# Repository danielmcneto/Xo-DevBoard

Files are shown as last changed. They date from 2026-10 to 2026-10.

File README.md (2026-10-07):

# Xo-DevBoard

Xo-DevBoard Rendering

**Xo-DevBoard** is a compact, custom ESP32-WROOM-32 development board featuring an integrated display header designed specifically for real-time sensor debugging without relying on a tethered PC monitor.

---

## The Problem & The Solution

**Tired of constantly alt-tabbing to your Serial Monitor just to check if a sensor value is updating?**  
Traditional devboards force you to keep your laptop plugged in during basic hardware debugging. The **Xo-DevBoard** solves this by providing a dedicated display interface (J4) directly on the board. Plug in a mini OLED or TFT screen, flash your code, and read live telemetry anywhere—completely standalone.

---

## Features & Hardware Highlights

* **Brain:** ESP32-WROOM-32 module (Wi-Fi + Bluetooth BLE).
* **Integrated Display Interface (J4 Header):** Dedicated 8-pin connector supporting I2C/SPI display modules.
* **On-board USB-to-UART Converter:** CH340C chip with an automated DTR/RTS auto-reset circuit
* **Power Management:** Modern USB-C connector with ESD/overcurrent protection.
* **User Controls:** Tactile Reset (EN) and Boot (GPIO0) buttons.
* **Full Breakout:** Dual 1x15 pin headers breaking out all usable ESP32 GPIOs for breadboard prototyping.

---

<!--## Display Header Pinout (J4)

The built-in display connector (**J4**) is routed to the following ESP32 pins[cite: 2]:

| Pin # | Header Label | ESP32 GPIO | Typical Usage (I2C / SPI) |
| :---: | :---: | :---: | :---: |
| 1 | GND | GND | Ground[cite: 2] |
| 2 | 3.3V | +3.3VA | Power Supply (3.3V)[cite: 2] |
| 3 | D18 | GPIO18 | SDA (I2C) / MOSI (SPI)[cite: 2] |
| 4 | D23 | GPIO23 | SCL (I2C) / SCK (SPI)[cite: 2] |
| 5 | D2 | GPIO02 | Reset / General IO[cite: 2] |
| 6 | D4 | GPIO04 | Data / Command (DC)[cite: 2] |
| 7 | D5 | GPIO05 | Chip Select (CS)[cite: 2] |
| 8 | 3.3V | +3.3VA | Auxiliary Power[cite: 2] |

--->

## Project Status & Firmware

This repository contains:
1. **KiCad Production Files:** Schematic (`.kicad_sch`), PCB layout (`.kicad_pcb`), and Gerber files for manufacturing.
2. **Starter Firmware:** A C++/PlatformIO demo program that initializes the display, tests onboard peripherals, and renders a `"Hello World!"` telemetry screen.

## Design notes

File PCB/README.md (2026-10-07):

## Here you will find the files of the pcb

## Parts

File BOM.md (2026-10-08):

# Xo-DevBoard – bill of materials

<!-- Generated by Half Life from project cmuv2anbv0cnf01smwlqq86t9. Edits here are overwritten on the next sync. -->
<!-- Generated: 2026-10-08T13:36:38.834Z -->

> [!NOTE]
> This parts list is mirrored from [Half Life](https://halflife.hackclub.com). Editing it here will not change the platform's copy, and the next sync overwrites this file.

| Week | Tier | Parts funding |
| --- | --- | --- |
| Week 1 | Tier 1 | $30.00 |

| Part | What it's for | Qty | Unit | Total | Vendor |
| --- | --- | --- | --- | --- | --- |
| [TFT display](https://www.amazon.com/Display-Module-240x240-Interface-Arduino/dp/B0DN9NMBFW/ref=sr_1_3?sr=8-3) | for the built-in display | 1 | $7.99 | $7.99 | [AMAZON](https://www.amazon.com/Display-Module-240x240-Interface-Arduino/dp/B0DN9NMBFW/ref=sr_1_3?sr=8-3) |
| **Parts subtotal** | — | — | — | **$7.99** | — |
| **Tax & shipping** | — | — | — | **$20.00** | — |
| **Total** | — | — | — | **$27.99** | — |

$2.01 left of the tier's funding.

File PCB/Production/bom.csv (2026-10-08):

Designator | Footprint | Quantity | Value | LCSC Part #
BOOT, RST | SW_Push_SPST_NO_Alps_SKRK | 2 | SW_Push
C3, C4, C6, C7, C8 | 0603 | 5 | 100nF
C5 | CP_EIA-3216-10_Kemet-I | 1 | 10uF/16v
D2 | D_SOD-123 | 1 | B5819W
D3, D4 | 0603 | 2 | LED
J1 | USB_C_Receptacle_HRO_TYPE-C-31-M-12 | 1 | USB_C_Receptacle_USB2.0_16P
J2, J3 | PinHeader_1x15_P2.54mm_Vertical | 2 | Conn_01x15
J4 | PinSocket_1x08_P2.54mm_Vertical | 1 | DISPLAY
Q1, Q2 | SOT-23 | 2 | SS8050
R2, R3 | 0603 | 2 | 5K1
R4 | 0603 | 1 | 1K
R5, R6, R8 | 0603 | 3 | 10K
R9 | 0603 | 1 | 200R
U1 | SOIC-16_3.9x9.9mm_P1.27mm | 1 | CH340C
U2 | ESP32-WROOM-32 | 1 | ESP32-WROOM-32
U3 | SOT-223-3_TabPin2 | 1 | AMS1117-3.3

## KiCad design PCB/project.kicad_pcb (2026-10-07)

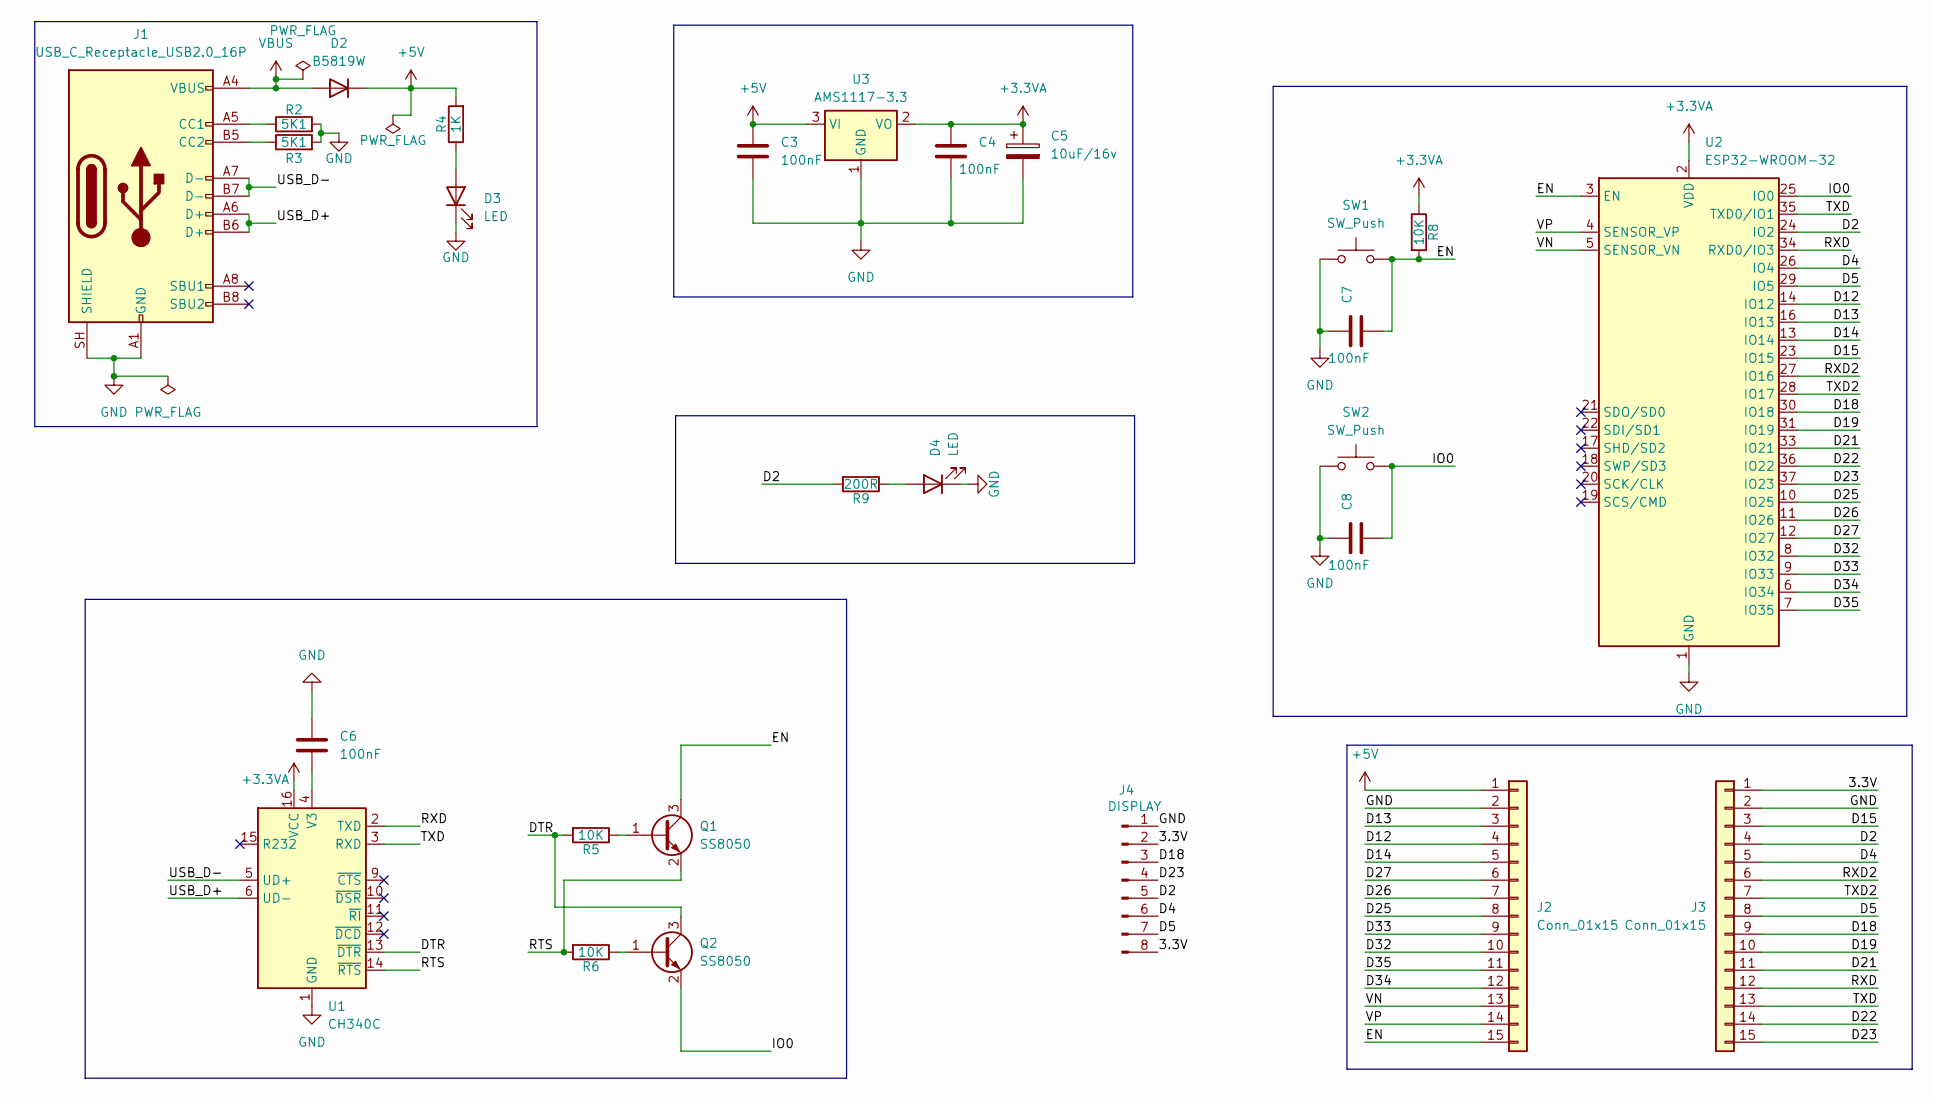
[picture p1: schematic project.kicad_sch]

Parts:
C3, C4, C6, C7, C8: 100nF; C_0603_1608Metric
C5: 10uF/16v; CP_EIA-3216-10_Kemet-I
D2: B5819W; D_SOD-123
D3, D4: LED; LED_0603_1608Metric
J1: USB_C_Receptacle_USB2.0_16P; USB_C_Receptacle_HRO_TYPE-C-31-M-12
J2, J3: Conn_01x15; PinHeader_1x15_P2.54mm_Vertical
J4: DISPLAY; PinSocket_1x08_P2.54mm_Vertical
Q1, Q2: SS8050; SOT-23
R2, R3: 5K1; R_0603_1608Metric
R4: 1K; R_0603_1608Metric
R5, R6, R8: 10K; R_0603_1608Metric
R9: 200R; R_0603_1608Metric
SW1, SW2: SW_Push; SW_Push_SPST_NO_Alps_SKRK
U1: CH340C; SOIC-16_3.9x9.9mm_P1.27mm
U2: ESP32-WROOM-32
U3: AMS1117-3.3; SOT-223-3_TabPin2

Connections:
+3.3VA: C4.1, C5.1, R8.1, U1.16 (VCC), U2.2 (VDD), U3.2 (VO)
+5V: C3.1, D2.1 (K), J2.1, R4.2, U3.3 (VI)
/3.3V: J3.1, J4.2, J4.8
/D2: J3.4, J4.5, R9.2, U2.24 (IO2)
/D4: J3.5, J4.6, U2.26 (IO4)
/D5: J3.8, J4.7, U2.29 (IO5)
/D12: J2.4, U2.14 (IO12)
/D13: J2.3, U2.16 (IO13)
/D14: J2.5, U2.13 (IO14)
/D15: J3.3, U2.23 (IO15)
/D18: J3.9, J4.3, U2.30 (IO18)
/D19: J3.10, U2.31 (IO19)
/D21: J3.11, U2.33 (IO21)
/D22: J3.14, U2.36 (IO22)
/D23: J3.15, J4.4, U2.37 (IO23)
/D25: J2.8, U2.10 (IO25)
/D26: J2.7, U2.11 (IO26)
/D27: J2.6, U2.12 (IO27)
/D32: J2.10, U2.8 (IO32)
/D33: J2.9, U2.9 (IO33)
/D34: J2.12, U2.6 (IO34)
/D35: J2.11, U2.7 (IO35)
/DTR: Q2.3 (C), R5.2, U1.13 (~DTR)
/EN: C7.2, J2.15, Q1.3 (C), R8.2, SW1.2, U2.3 (EN); also elsewhere on the board
/IO0: C8.2, Q2.2 (E), SW2.2, U2.25 (IO0); also elsewhere on the board
/RTS: Q1.2 (E), R6.2, U1.14 (~RTS)
/RXD: J3.12, U1.2 (TXD), U2.34 (RXD0/IO3)
/RXD2: J3.6, U2.27 (IO16)
/TXD: J3.13, U1.3 (RXD), U2.35 (TXD0/IO1)
/TXD2: J3.7, U2.28 (IO17)
/USB_D+: J1.A6 (D+), J1.B6 (D+), U1.6 (UD-)
/USB_D-: J1.A7 (D-), J1.B7 (D-), U1.5 (UD+)
/VN: J2.13, U2.5 (SENSOR_VN)
/VP: J2.14, U2.4 (SENSOR_VP)
GND: C3.2, C4.2, C5.2, C6.1, C7.1, C8.1, D3.1 (K), D4.1 (K), J1.A1 (GND), J1.A12 (GND), J1.B1 (GND), J1.B12 (GND), J1.SH (SHIELD), J2.2, J3.2, J4.1, R2.2, R3.2, SW1.1, SW2.1, U1.1 (GND), U2.1 (GND), U2.15 (GND), U2.38 (GND), U2.39 (GND), U3.1 (GND); also elsewhere on the board
unnamed: D3.2 (A), R4.1
unnamed: D4.2 (A), R9.1
unnamed: J1.A5 (CC1), R2.1
unnamed: J1.B5 (CC2), R3.1
unnamed: Q1.1 (B), R5.1
unnamed: Q2.1 (B), R6.1
unnamed: C6.2, U1.4 (V3)
VBUS: D2.2 (A), J1.A4 (VBUS), J1.A9 (VBUS), J1.B4 (VBUS), J1.B9 (VBUS)

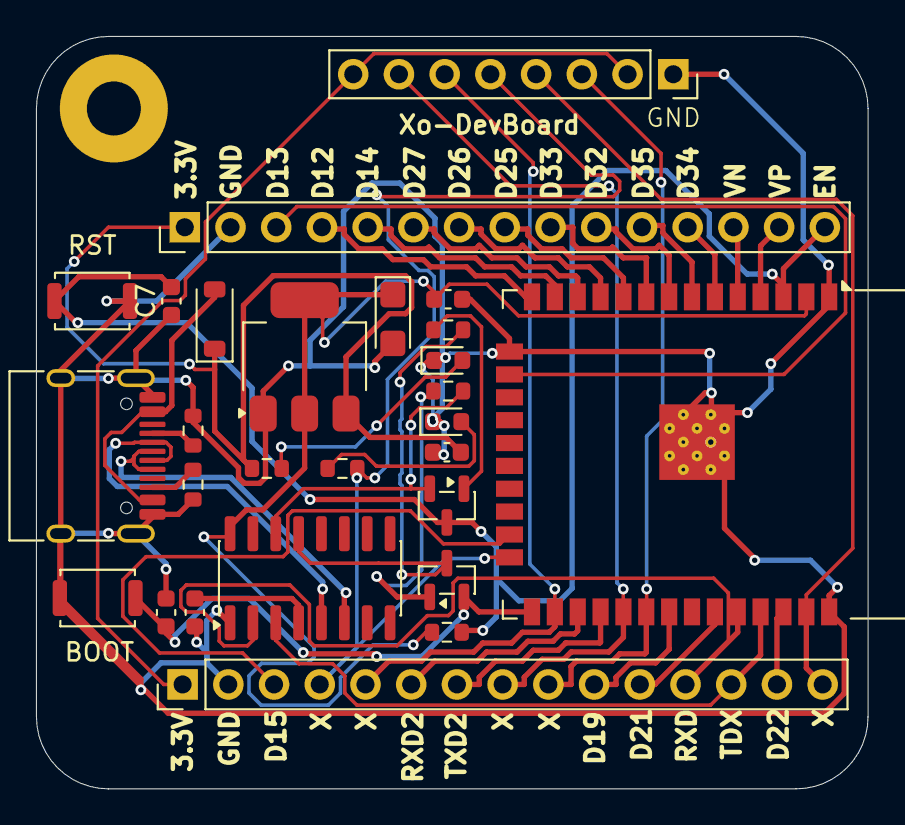
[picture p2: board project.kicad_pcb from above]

Board: 2 copper layers, 46.2 x 41.8 mm, 28 parts (1 on the bottom side), 43 nets.

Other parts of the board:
BOOT: SW_Push; SW_Push_SPST_NO_Alps_SKRK
RST: SW_Push; SW_Push_SPST_NO_Alps_SKRK
THAT SHIT WAS HARD TO BUILT: LOGO; draw

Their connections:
/EN: RST.2; also elsewhere on the board
/IO0: BOOT.2; also elsewhere on the board
GND: BOOT.1, RST.1; also elsewhere on the board

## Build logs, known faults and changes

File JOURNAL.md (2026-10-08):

# Xo-DevBoard – devlog

<!-- Generated by Half Life from project cmuv2anbv0cnf01smwlqq86t9. Edits here are overwritten on the next sync. -->
<!-- Generated: 2026-10-07T21:22:15.961Z -->

> [!NOTE]
> This devlog is mirrored from [Half Life](https://halflife.hackclub.com). Editing it here will not change the platform's copy, and the next sync overwrites this file.

> A custom, minimalist ESP32-based development board designed for rapid prototyping in robotics and IoT.Hopefully it will feature an integrated USB-to-UART bridge, auto-reset/boot circuitry, clean 3.3V power regulation with decoupling capacitors, and broken-out GPIO pin headers for direct breadboard/sensor integration.

| Week | Tier | Hours logged | Entries |
| --- | --- | --- | --- |
| Week 1 | Tier 1 | 6.34h | 5 |

## Contents

1. [2026-10-05 – Work session](#2026-10-05-work-session)
2. [2026-10-05 – Work session](#2026-10-05-work-session)
3. [2026-10-06 – Work session](#2026-10-06-work-session)
4. [2026-10-07 – Work session](#2026-10-07-work-session)
5. [2026-10-07 – **Started coding the firmware**](#2026-10-07-started-coding-the-firmware)

## Design

### 2026-10-05 – Work session

**1.47h**

[Timelapse](https://lookout.hackclub.com/api/media/d1a9a978-26e2-413a-b301-4d7803d085b0/video.mp4)

### 2026-10-05 – Work session

**1.33h**

[Timelapse](https://lookout.hackclub.com/api/media/b6cb3c58-f377-4d1a-b813-6f6a1e455716/video.mp4)

### 2026-10-06 – Work session

**0.52h**

[Timelapse](https://lookout.hackclub.com/api/media/f1ac6d8b-2952-44ee-9bc7-67228432e873/video.mp4)

### 2026-10-07 – Work session

**1.02h**

[Timelapse](https://lookout.hackclub.com/api/media/4f2e23b2-f054-4917-a517-2179c9cd7979/video.mp4)

### 2026-10-07 – **Started coding the firmware**

**2h**

**Started coding the firmware**

The main objetive with the firmware is test if the board is working nice and smooth

This first codes test the built-in display

with that code being uploaded to the board we should be able the get a text on the display
-----
**That is the GitHub repo**

Here you can view all info about the project, how I made it and all the project files

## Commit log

2026-10-07 Add initial README for PCB project
2026-10-07 Added kicad files
    [project.kicad_pcb, project.kicad_sch]
2026-10-07 Fix formatting in README.md for KiCad files section
2026-10-07 Added production files
    [project-B_Cu.gbr, project-B_Mask.gbr, project-B_Paste.gbr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]
2026-10-08 added bom.csv
    [bom.csv]
2026-10-11 Updated the PCB files
2026-10-11 Added v2 project files(.pcb .pro .sch)
